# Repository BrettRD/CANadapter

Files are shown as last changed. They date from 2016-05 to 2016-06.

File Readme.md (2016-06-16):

# CANadapter

This is a basic CAN bus adapter based on the MCP2515 and the MCP2551.
The design is largely compatible with the Sparkfun CAN-BUS Shield for the sake of everyone's sanity.

The connectors are intended to be pin-compatible with Pmod, but there doesn't seen to be a standard or even defacto pinout for CANbus on Pmod online.

Board images generated by gerblook.org
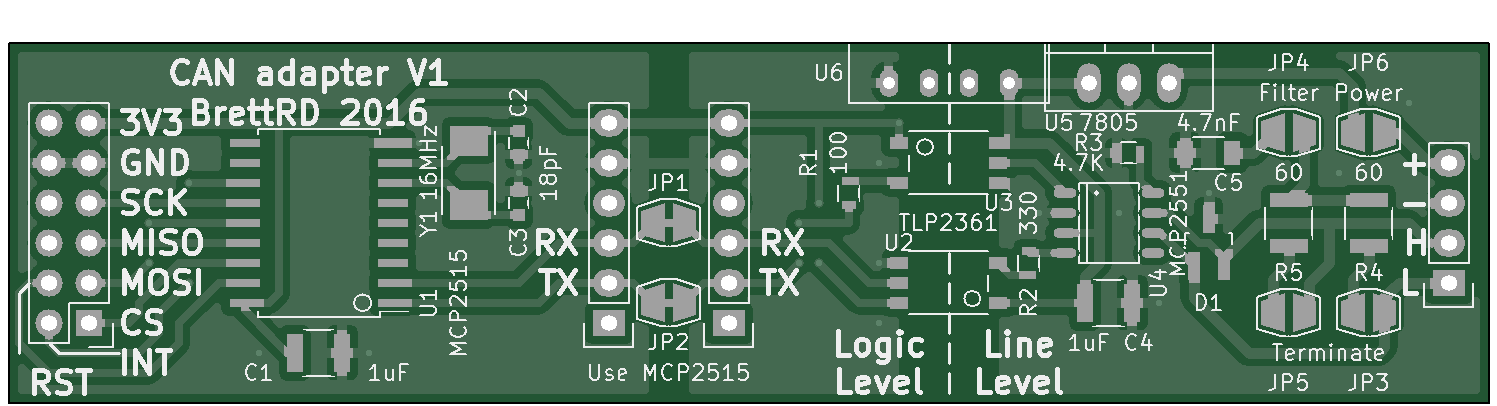
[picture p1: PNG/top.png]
Board Front

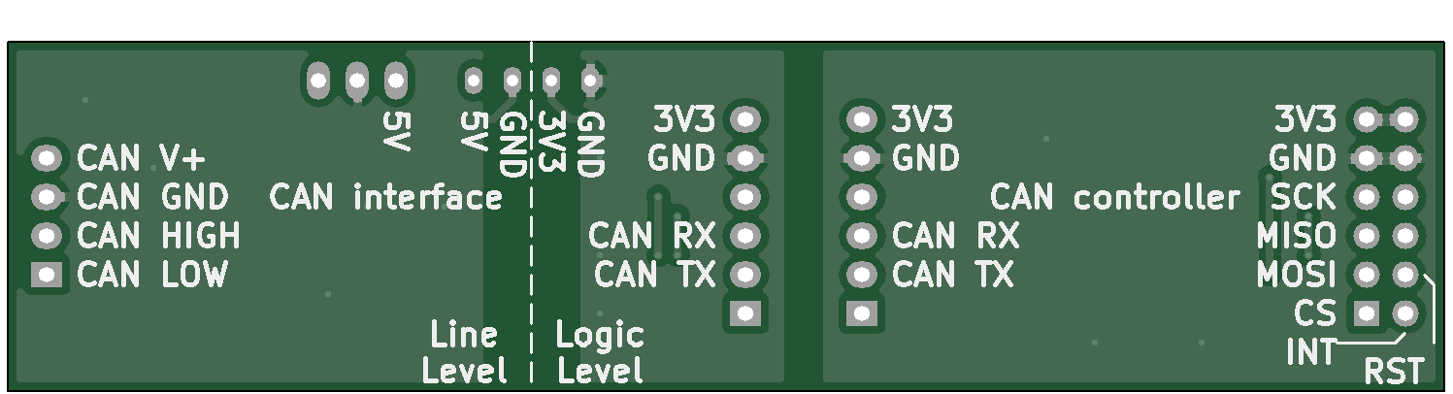
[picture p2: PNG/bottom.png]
Board Rear


##Major design goals:
* Full electrical isolation
* Hardy CAN front-end
* Support CAN bus development on the FPGA driven icoBoard.

## Parts List:
### CAN interface:
* 1x MCP2551 soic8 - CAN interface chip
* 1x PESD1CAN sot23 - TVS diode
* 2x TLP2361 fast optocoupler - optoisolation
* 2x 60R 1210 resistor - termination resistors
* 1x 4.7nF 1206 capacitor - Common mode filter
* 1x 1uF 1206 capacitor
* 1x 100R 0603 resistor
* 1x 330R 0603 resistor
* 1x 4K7 0603 resistor
* 1x 4pin header

### CAN Controller:
* 1x MCP2515 soic18 7.5mm - CAN controller IC
* 1x 16MHz 5032 crystal
* 1x 1uF 1206 capacitor
* 2x 18pF 0603 capacitor
* 1x 2x6pin header

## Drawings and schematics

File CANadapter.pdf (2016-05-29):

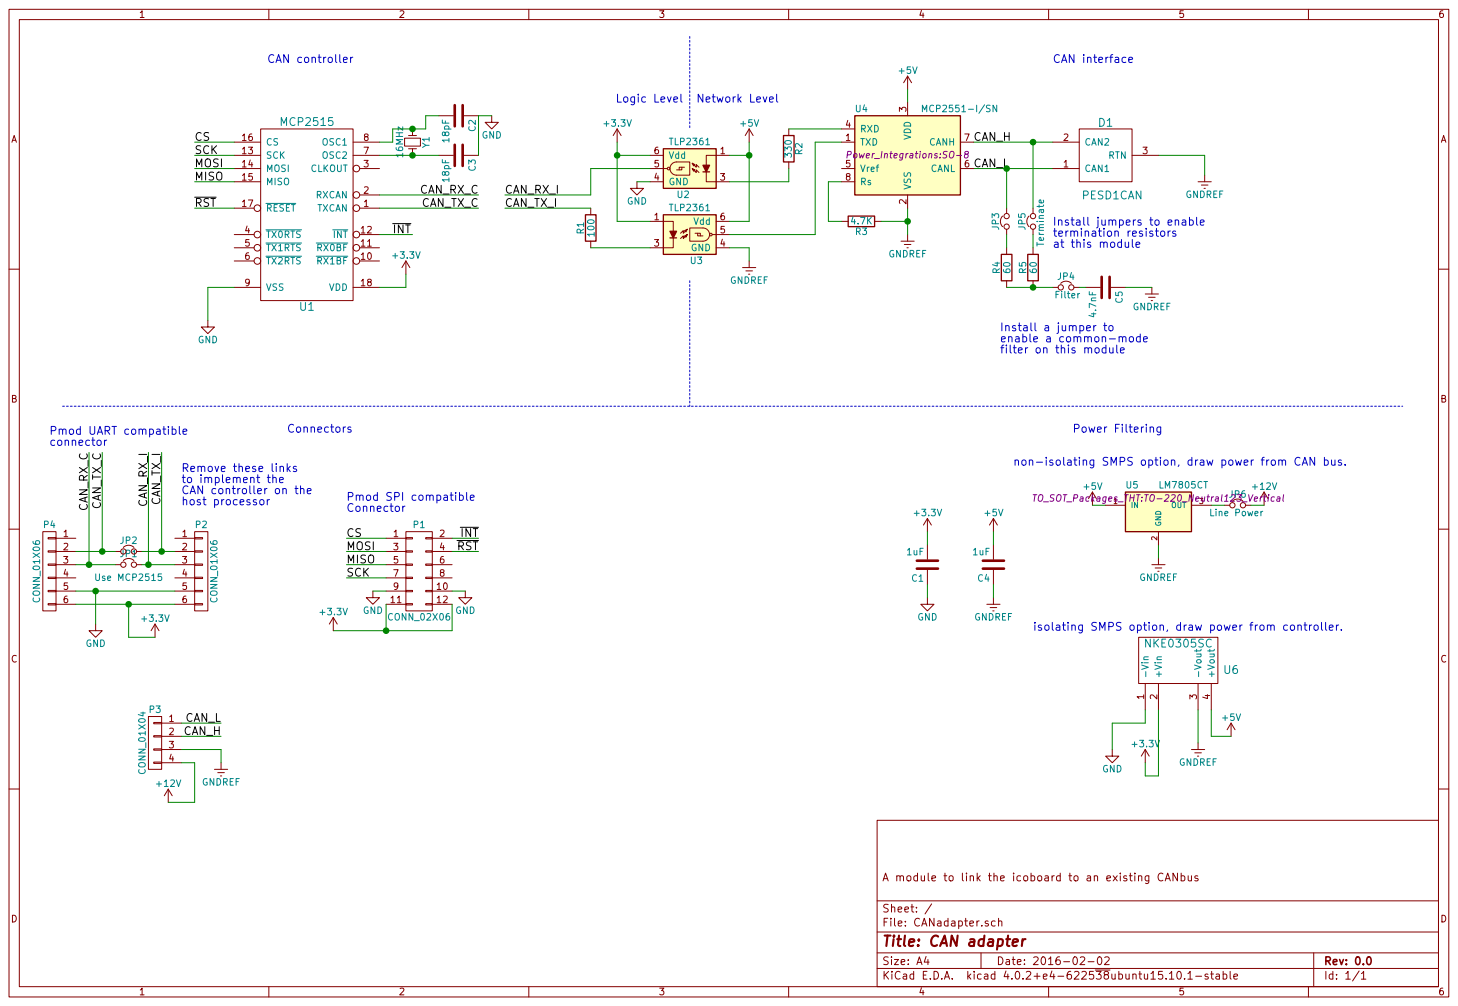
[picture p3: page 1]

3 RXD 4 Vref 5 CANL 6 CANH 7 Rs 8 U4 MCP2551-I/SN

termination resistors at this module

filter on this module Remove these links

to implement the
+5V GNDREF
CAN controller on the
host processor

INT Pmod SPI compatible
Connector

isolating SMPS option, draw power from controller.

File: CANadapter.sch Sheet: / A module to link the icoboard to an existing CANbus

Id: 1/1 Title: CAN adapter

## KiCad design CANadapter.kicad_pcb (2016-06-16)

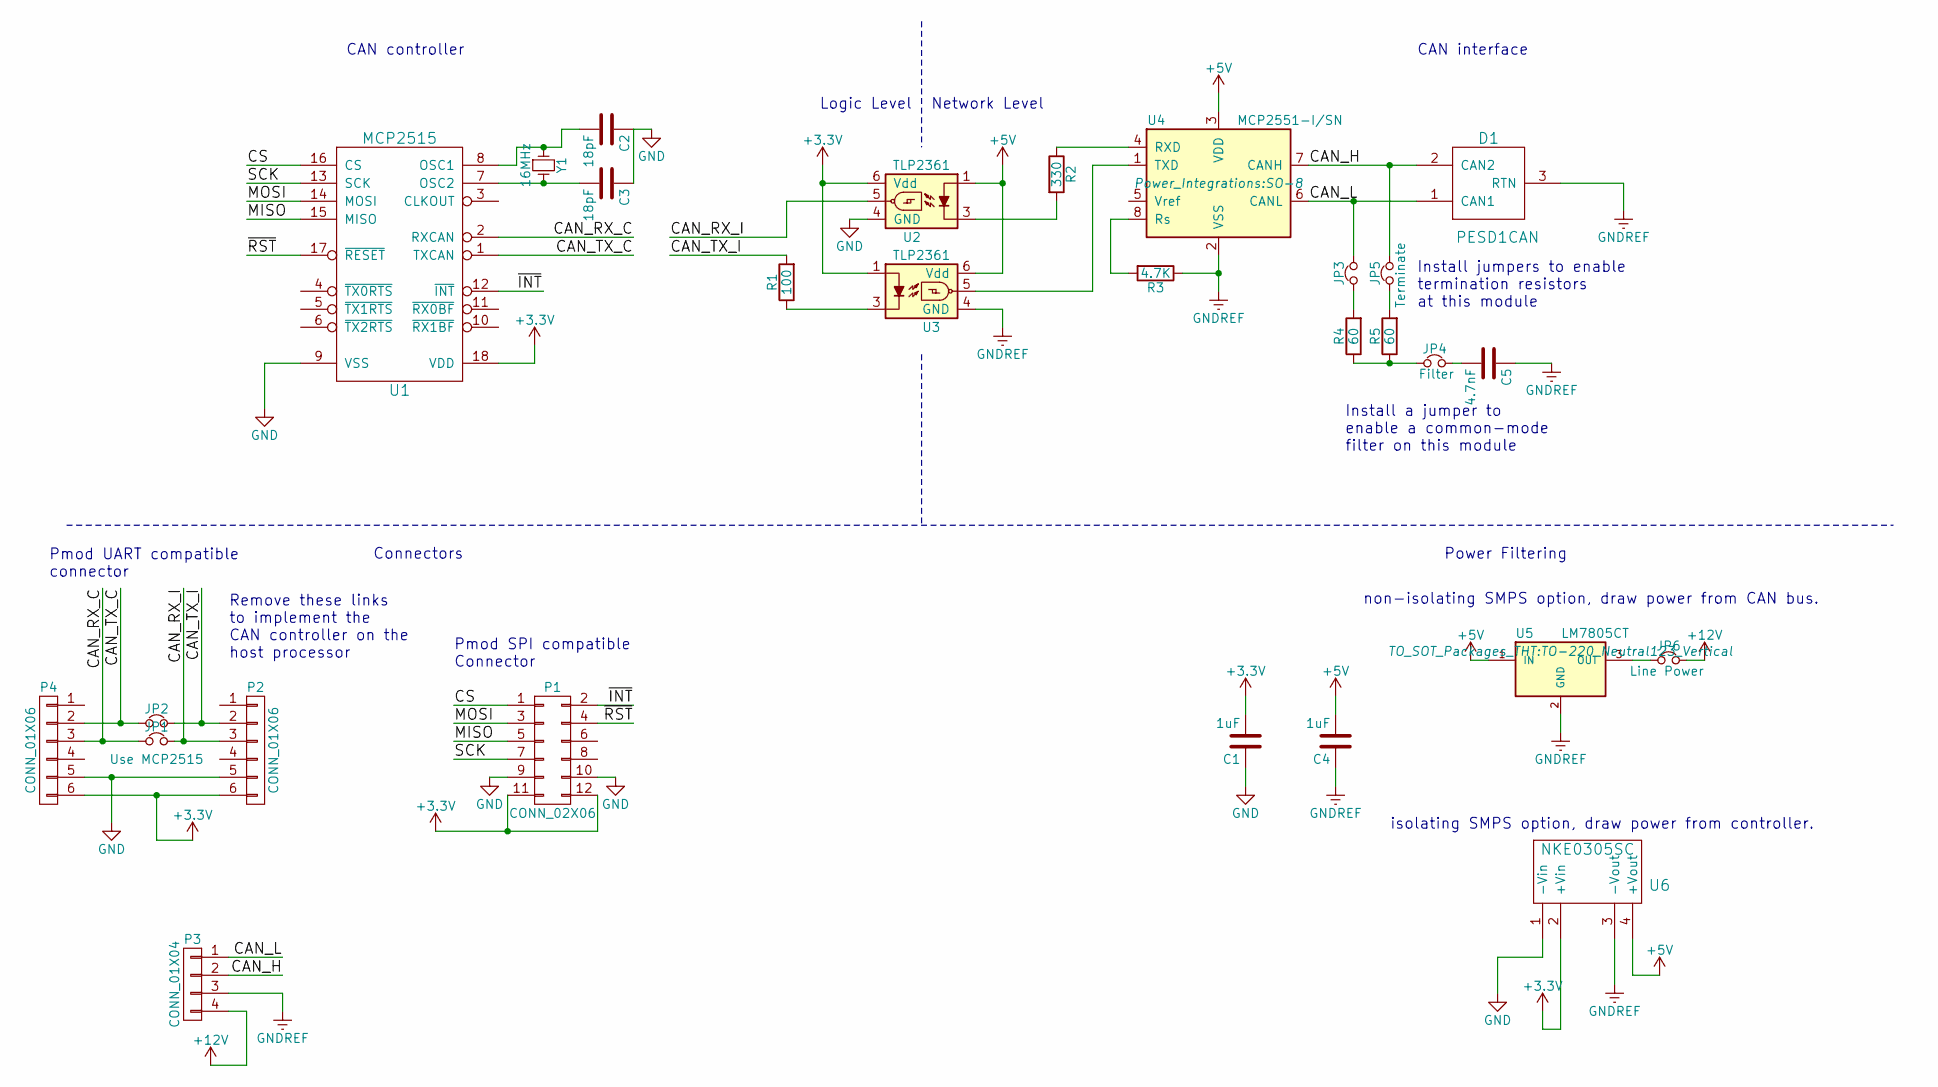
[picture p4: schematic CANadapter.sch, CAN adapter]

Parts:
C1, C4: 1uF; C_1210
C2, C3: 18pF; C_0603
C5: 4.7nF; C_1206
D1: PESD1CAN; SOT-23_Handsoldering
JP1, JP2: Use MCP2515; JumperSingleClosed
JP3, JP5: Terminate; JumperSingle
JP4: Filter; JumperSingle
JP6: Line Power; JumperSingle
P1: CONN_02X06; Pin_Header_Straight_2x06
P2, P4: CONN_01X06; Pin_Header_Straight_1x06
P3: CONN_01X04; Pin_Header_Straight_1x04
R1: 100; R_0603
R2: 330; R_0603
R3: 4.7K; R_0603
R4, R5: 60; R_1210
U1: MCP2515; SOIC-18_7.5x11.6mm_Pitch1.27mm
U2, U3: TLP2361; soic-5
U4: MCP2551-I/SN; SO-8
U5: LM7805CT; TO-220_Neutral123_Vertical
U6: NKE0305SC; Murata_SIL
Y1: 16MHz; Crystal_SMD_5032_2Pads

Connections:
+3V3: C1.2, P1.11, P1.12, P2.6, P4.6, U1.18 (VDD), U2.6 (Vdd), U3.1, U6.2 (+Vin)
+5V: C4.2, U2.1, U3.6 (Vdd), U4.3 (VDD), U5.1 (IN), U6.4 (+Vout)
+12V: JP6.1, P3.4
/CAN_H: D1.2 (CAN2), JP5.1, P3.2, U4.7 (CANH)
/CAN_L: D1.1 (CAN1), JP3.2, P3.1, U4.6 (CANL)
/CAN_RX_C: JP1.1, P4.3, U1.2 (RXCAN)
/CAN_RX_I: JP1.2, P2.3, U2.5
/CAN_TX_C: JP2.1, P4.2, U1.1 (TXCAN)
/CAN_TX_I: JP2.2, P2.2, R1.2
/CS: P1.1, U1.16 (CS)
/MISO: P1.5, U1.15 (MISO)
/MOSI: P1.3, U1.14 (MOSI)
/SCK: P1.7, U1.13 (SCK)
/~INT: P1.2, U1.12 (~INT)
/~RST: P1.4, U1.17 (~RESET)
GND: C1.1, C2.1, C3.1, P1.9, P1.10, P2.5, P4.5, U1.9 (VSS), U2.4 (GND), U6.1 (-Vin)
GNDREF: C4.1, C5.1, D1.3 (RTN), P3.3, R3.1, U3.4 (GND), U4.2 (VSS), U5.2 (GND), U6.3 (-Vout)
unnamed: C2.2, U1.8 (OSC1), Y1.1
unnamed: C3.2, U1.7 (OSC2), Y1.2
unnamed: C5.2, JP4.2
unnamed: JP3.1, R4.2
unnamed: JP4.1, R4.1, R5.1
unnamed: JP5.2, R5.2
unnamed: JP6.2, U5.3 (OUT)
unnamed: R1.1, U3.3
unnamed: R2.1, U4.4 (RXD)
unnamed: R2.2, U2.3
unnamed: R3.2, U4.8 (Rs)
unnamed: U3.5, U4.1 (TXD)

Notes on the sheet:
Pmod UART compatible connector
Logic Level
Network Level
Install jumpers to enable termination resistors at this module
Install a jumper to enable a common-mode filter on this module
Remove these links to implement the CAN controller on the host processor
non-isolating SMPS option, draw power from CAN bus.
Pmod SPI compatible Connector
CAN controller
CAN interface
Connectors
Power Filtering
isolating SMPS option, draw power from controller.

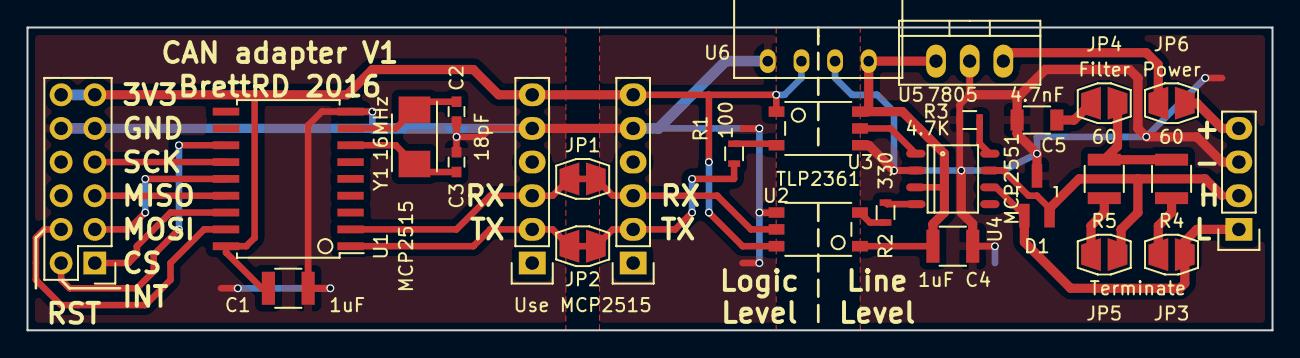
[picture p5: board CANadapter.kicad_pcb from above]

Board: 2 copper layers, 94.0 x 22.9 mm, 28 parts (0 on the bottom side), 29 nets.

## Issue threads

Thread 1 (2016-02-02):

Choose an optocoupler

BrettRD, 2016-02-02:
The optoisolator in the schematic is just a place-holder.

BrettRD, 2016-03-02:
Using the TLC2361 digital output optocoupler.
2.7V to 5V operating range, and plenty fast.

Closed 2016-03-02.

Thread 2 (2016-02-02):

Voltage 3.3V < 5V

emard, 2016-02-02:
MCP2551 transciever is for 5V operation while
PMOD power is 3.3V

I'd suggest to replace 2551 with a different
3.3V compliant transciever, usually they are
SMD don't know of any DIL pacage with 3.3V

BrettRD, 2016-02-02:
Thanks for that,
CAN bus line voltages can vary between applications; 5V is the most common, but you do find 24V networks in the wild.
This circuit runs fully isolated so the FPGA side will be happy between 2v7~5v5 as supplied by the host processor, while the line side is powered by the line.
The MCP2515 has the 2v7 lower limit, but I'm going to try to push the raw CANtx/rx (optoisolated IO) limits below 1v8.
(I had a bad experience with a non-isolated network, magic smoke came out all over the place, all at once)

emard, 2016-02-02:
OK then I'd suggest some small switching regulator
7-40V -> 5V so the real can will properly power the
MCP2551

also adjust some resistors, 120ohm is standard impedance
for the line
100 ohm for 3.3V side of optoisolator should be a bit larger
on 5V side...

On Tue, Feb 2, 2016 at 3:16 PM, Brett Downing <notifications@github.com>
wrote:

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

BrettRD, 2016-02-03:
I've added a linear reg to the schematic, it's a place-holder for now, the 78L05 will only barely drive the MCP2551.  It also needs additional spike and over-current protection.
I wasn't planning on making this a super-deluxe adapter, so I'm hesitant to build a proper SPMS on-board.
Murata make a very nice 7805-drop-in-replacement module, I haven't killed one yet.
I may just stick that footprint on.

Closed 2016-06-16.

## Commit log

2016-02-02 Basic structure of schematic
    [CANadapter.kicad_pcb, CANadapter.sch]
2016-02-02 added schematic PDF
    [CANadapter.sch]
2016-02-03 Changed CAN termination, added resonator and jumpers
    [CANadapter.sch]
2016-02-03 Added basic voltage regulator on line side
    [CANadapter.sch]
2016-03-02 Changed CANtx/rx connector, tidied the schematic
    [CANadapter.sch]
2016-03-02 most footprints associated and roughly placed
    [CANadapter.kicad_pcb, CANadapter.sch]
2016-03-21 corrected connectivity and pin numbering, placed parts
    [CANadapter.kicad_pcb, CANadapter.sch]
2016-03-22 Partial layout
    [CANadapter.kicad_pcb]
2016-05-21 substituted footprints, layout first pass complete
    [CANadapter.kicad_pcb, CANadapter.sch]
2016-05-29 added isolating smps, moved jumpers, added ground pours
    [CANadapter.kicad_pcb, CANadapter.sch]
2016-06-16 finished routing, improved silk
    [CANadapter-B.Cu.gbl, CANadapter-B.Mask.gbs, CANadapter-B.SilkS.gbo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]
2016-06-16 improved silk
    [CANadapter.kicad_pcb, CANadapter.sch]
2016-06-16 ready for beta round
    [CANadapter-B.Cu.gbl, CANadapter-B.Mask.gbs, CANadapter-B.SilkS.gbo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]
